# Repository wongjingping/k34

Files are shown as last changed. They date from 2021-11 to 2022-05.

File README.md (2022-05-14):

# k34

This project contains the pcb designs for the k34 keyboard. The k34 is a unibody, column-staggered, high-profile, 3d-printed, tray-mount keyboard with 34 keys.

`orient.py` contains a python script I used to programmatically arrange the switch and diode footprints. Traces were hand-connected.

`k34/plate and case reference` contains the exported svg's that I imported into fusion360 for modeling the case and plate files. 

`case` contains the stl files I used for the plate and case. The case supports the sides/outline of the pcb and fits well but isn't secured (ie would be fine if you're not planning to transport/move it around a lot). Note that the plate is non-symmetric and is adapted directly from the pcb's edge cut layer. 

## Firmware

- [zmk](https://github.com/wongjingping/zmk-config)

- [qmk](https://github.com/qmk/qmk_firmware/tree/master/keyboards/k34)

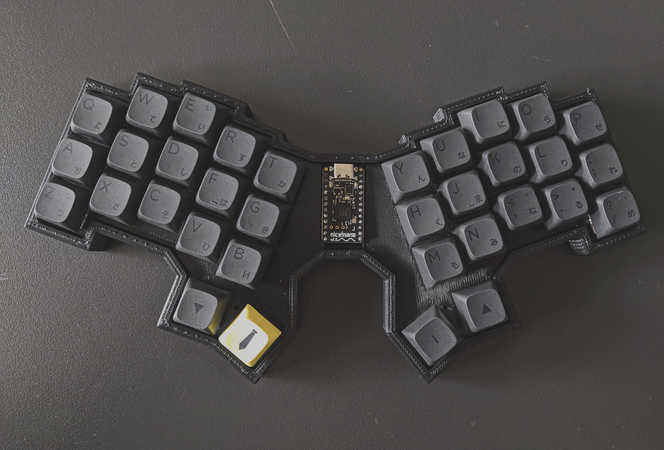
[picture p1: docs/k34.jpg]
K34 keyboard


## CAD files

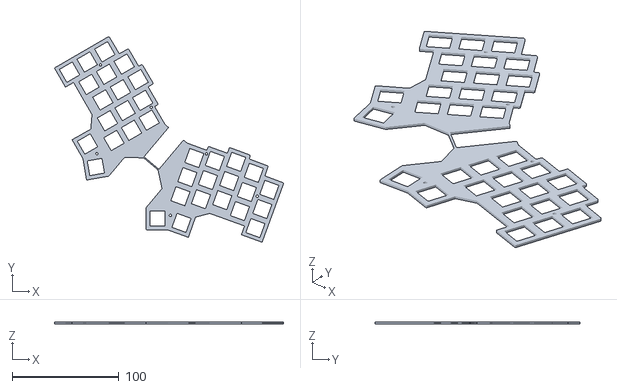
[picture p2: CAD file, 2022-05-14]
case/top plate non-sym v2.stl
214.9 x 192.8 x 1.60

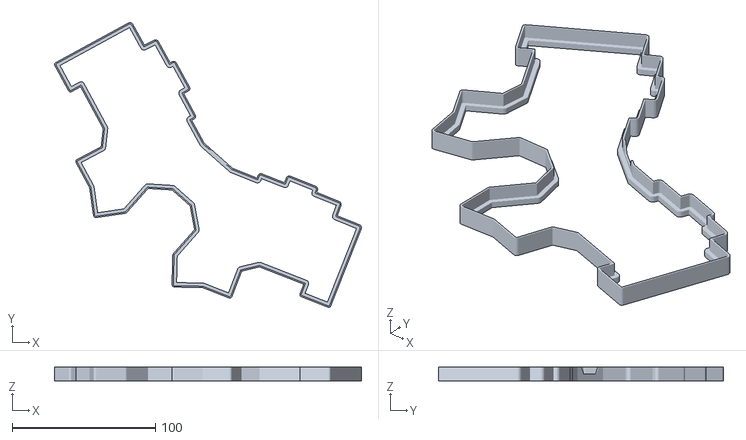
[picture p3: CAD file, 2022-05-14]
case/hollow case with cutout.stl
214.4 x 198.9 x 9.60

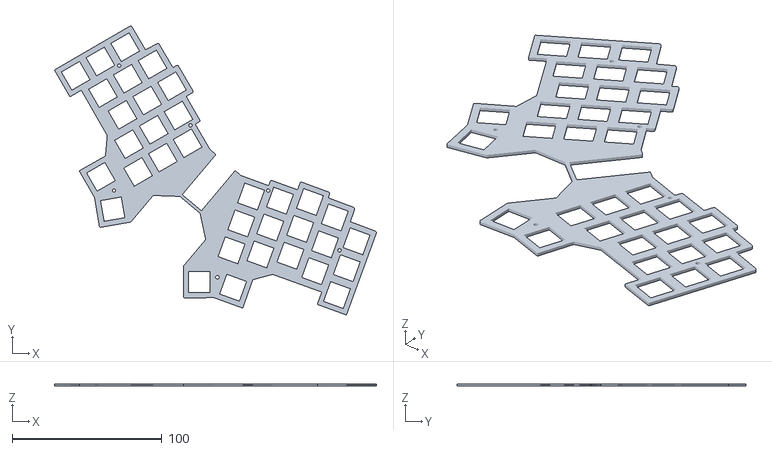
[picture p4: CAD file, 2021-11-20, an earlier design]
case/top plate non-sym v1.stl
214.9 x 192.8 x 1.60

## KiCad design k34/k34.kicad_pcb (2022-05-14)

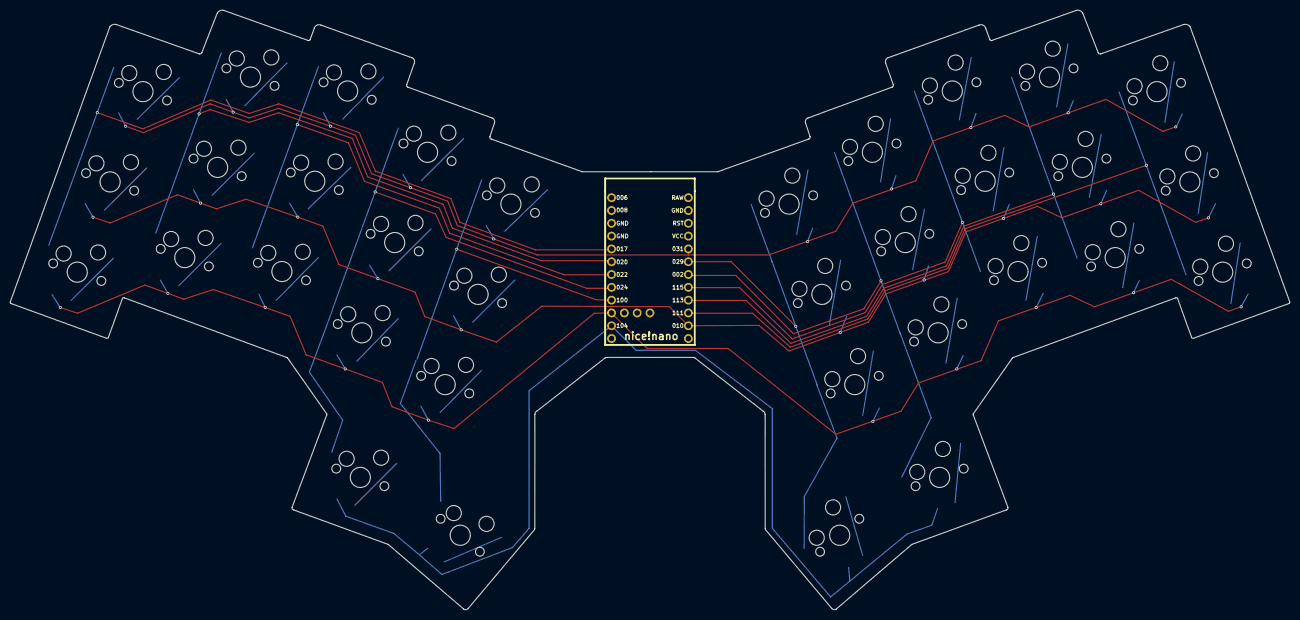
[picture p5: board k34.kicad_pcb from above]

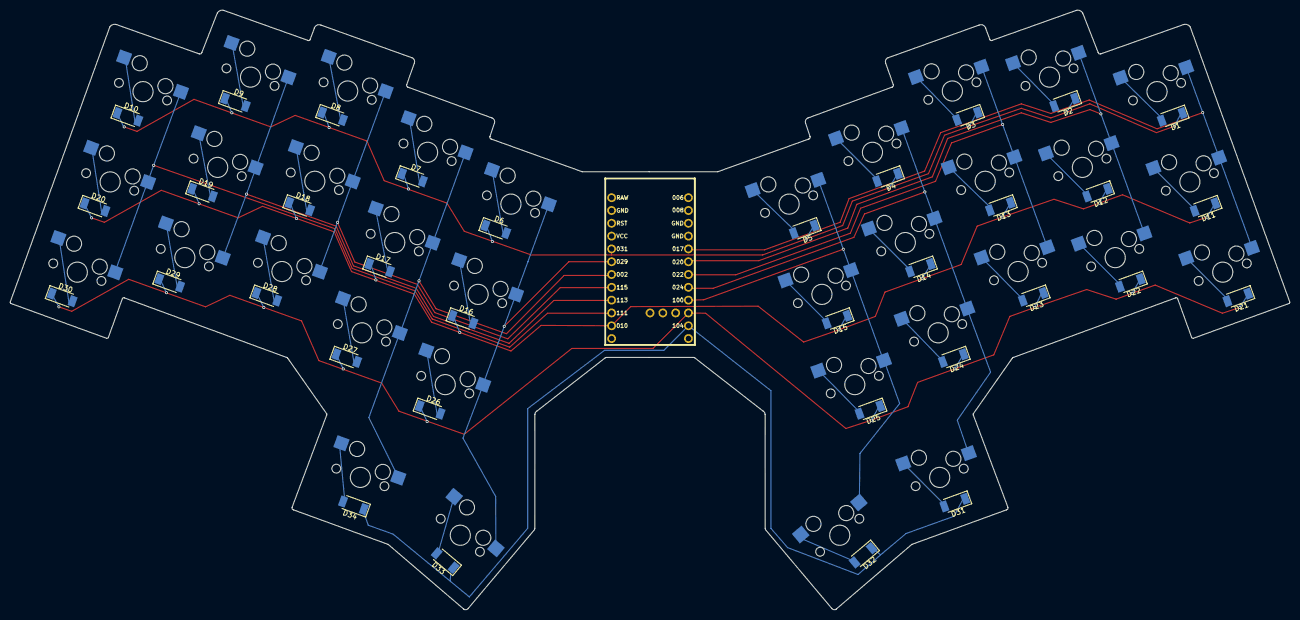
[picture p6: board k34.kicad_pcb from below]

Board: 2 copper layers, 253.8 x 118.9 mm, 69 parts (34 on the bottom side), 48 nets.

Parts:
D1, D2, D3, D4, D5, D6, D7, D8, D9, D10, D11, D12, D13, D14, D15, D16, D17, D18, D19, D20, D21, D22, D23, D24, D25, D26, D27, D28, D29, D30, D31, D32, D33, D34: D_Small; D_SOD-128
MX1, MX2, MX3, MX4, MX5, MX6, MX7, MX8, MX9, MX10, MX11, MX12, MX13, MX14, MX15, MX16, MX17, MX18, MX19, MX20, MX21, MX22, MX23, MX24, MX25, MX26, MX27, MX28, MX29, MX30, MX31, MX32, MX33, MX34: MX-NoLED; MXOnly-1U-Hotswap
U1: nice_nano

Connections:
/col0: MX1.1, MX11.1, MX21.1, U1.5
/col1: MX2.1, MX12.1, MX22.1, U1.6
/col2: MX3.1, MX13.1, MX23.1, U1.7
/col3: MX4.1, MX14.1, MX24.1, MX31.1, U1.8
/col4: MX5.1, MX15.1, MX25.1, MX32.1, U1.9
/col5: MX6.1, MX16.1, MX26.1, MX33.1, U1.19
/col6: MX7.1, MX17.1, MX27.1, MX34.1, U1.18
/col7: MX8.1, MX18.1, MX28.1, U1.17
/col8: MX9.1, MX19.1, MX29.1, U1.16
/col9: MX10.1, MX20.1, MX30.1, U1.15
/row0: D1.1, D2.1, D3.1, D4.1, D5.1, D6.1, D7.1, D8.1, D9.1, D10.1, U1.20
/row1: D11.1, D12.1, D13.1, D14.1, D15.1, D16.1, D17.1, D18.1, D19.1, D20.1, U1.14
/row2: D21.1, D22.1, D23.1, D24.1, D25.1, D26.1, D27.1, D28.1, D29.1, D30.1, U1.10
/row3: D31.1, D32.1, D33.1, D34.1, U1.11
unnamed: D1.2, MX1.2
unnamed: D2.2, MX2.2
unnamed: D3.2, MX3.2
unnamed: D4.2, MX4.2
unnamed: D5.2, MX5.2
unnamed: D6.2, MX6.2
unnamed: D7.2, MX7.2
unnamed: D8.2, MX8.2
unnamed: D9.2, MX9.2
unnamed: D10.2, MX10.2
unnamed: D11.2, MX11.2
unnamed: D12.2, MX12.2
unnamed: D13.2, MX13.2
unnamed: D14.2, MX14.2
unnamed: D15.2, MX15.2
unnamed: D16.2, MX16.2
unnamed: D17.2, MX17.2
unnamed: D18.2, MX18.2
unnamed: D19.2, MX19.2
unnamed: D20.2, MX20.2
unnamed: D21.2, MX21.2
unnamed: D22.2, MX22.2
unnamed: D23.2, MX23.2
unnamed: D24.2, MX24.2
unnamed: D25.2, MX25.2
unnamed: D26.2, MX26.2
unnamed: D27.2, MX27.2
unnamed: D28.2, MX28.2
unnamed: D29.2, MX29.2
unnamed: D30.2, MX30.2
unnamed: D31.2, MX31.2
unnamed: D32.2, MX32.2
unnamed: D33.2, MX33.2
unnamed: D34.2, MX34.2

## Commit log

2021-09-26 mark no connection
    [k34.sch]
2021-09-29 added plate pcb
    [k34-B_Cu.gbr, k34-B_Mask.gbr, k34-B_Paste.gbr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]
2021-10-03 added 3rd screw
    [k34-B_Cu.gbr, k34-B_Mask.gbr, k34-B_Paste.gbr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]
2021-10-03 added case files
    [bottom.stl]
2021-11-06 updated pcb design and added case/plate stl files, img
    [bottom.stl, case rotated.stl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]
2021-11-20 updated plates
    [hollow case 0.3mm offset.stl, top plate non-sym v1.stl, top plate rotated (252_248mm).stl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]
2022-05-14 updated schematic with wider diode
    [k34-B_Cu.gbr, k34-B_Mask.gbr, k34-B_Paste.gbr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]
2022-05-14 save kicad pro
    [k34.kicad_pcb]
2022-05-14 add case stl files
    [hollow case 0.3mm offset.stl, hollow case with cutout.stl, top plate non-sym v2.stl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]
